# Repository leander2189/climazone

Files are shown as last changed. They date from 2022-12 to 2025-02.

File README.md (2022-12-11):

# ClimaZone

Room console interface to Airzone control system, meant to replace old panels, like this one:

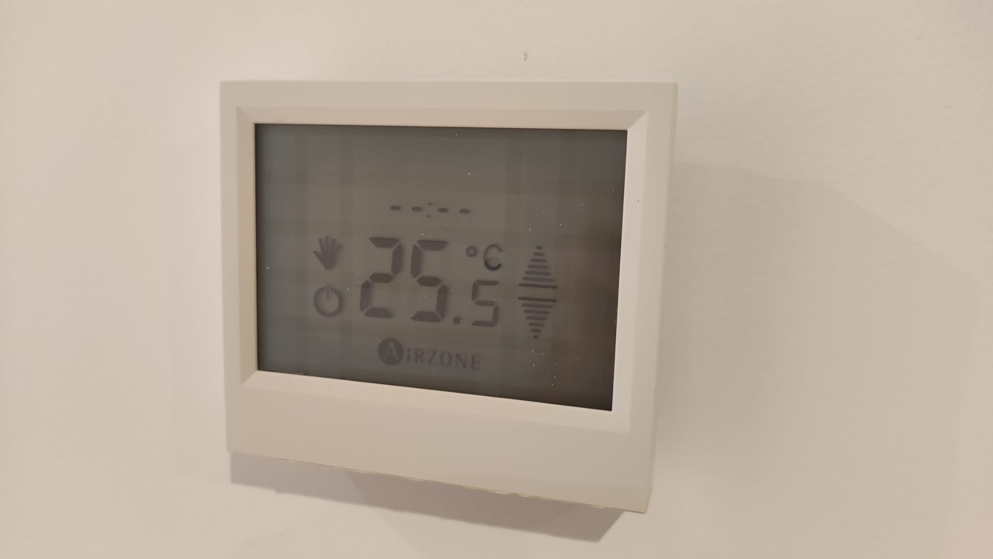
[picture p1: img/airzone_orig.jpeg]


## Bill of materials
 - ESP32 DevKit V1 DOIT
 - TFT Touch screen 2.8" 240x320 (SD + SPI)
 - BME280 I2C
 - DS18B20
 - PC817 x 4
 - 1k resistor x 4
 - 5k resistor x 1

## PCB Design
PCB design has been carried out using Kicad 6.0. The PCB is compatible both with master and slave consoles.

The temperature console is based on an ESP32 with a touch screen as an interface. It uses a DS18B20 for temperature measurement and a BME280 to measure humidity and pressure. Finally, the outputs are activated using PC817 optocouplers.

In the project there have been used 3 kicad libraries, which are already packaged:
 - https://gitlab.com/VictorLamoine/kicad/-/tree/master/ @ Victor Lamoine
 - https://github.com/colesnicov/kicad-TFT-Displays @ Colesnicov Denis
 - https://github.com/Pingoin/Pingolib-Kicad @ Pingoin

PCB Front               |  PCB Rear
:----------------------:|:-----------------------:
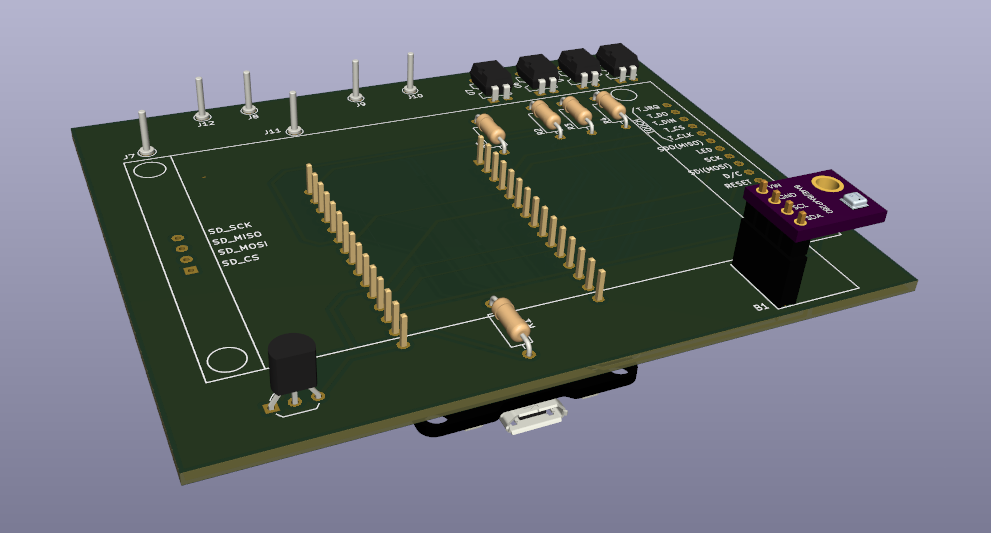
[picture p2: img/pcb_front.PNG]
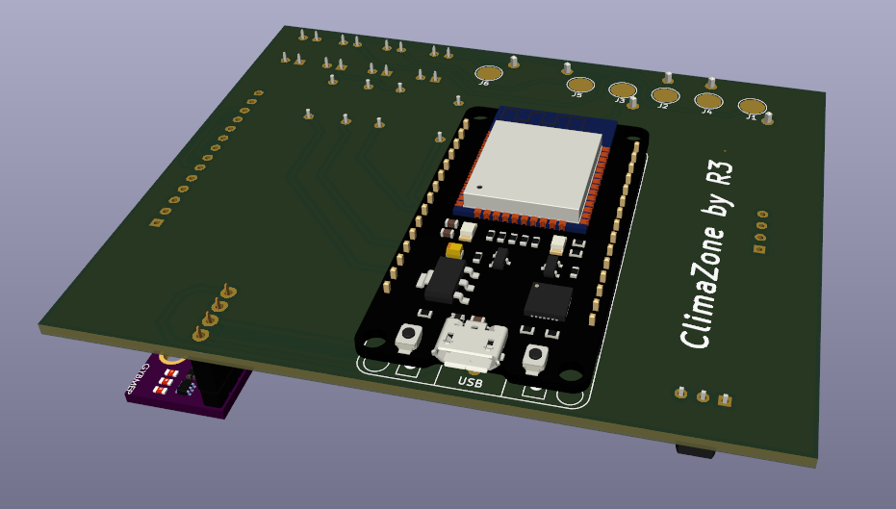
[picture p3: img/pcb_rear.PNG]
  |  

## Case design and installation
The case is designed to replace the old control panel, thus using the same interface bolts, as can be seen in the following picture.

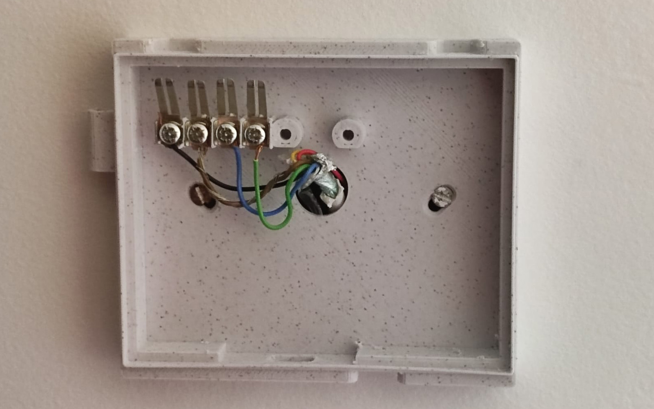
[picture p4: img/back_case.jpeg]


The design is composed of 2 elements, all of them can be 3D printed:
- The bottom part, which is bolted to the wall
- The top part, which encloses the PCB

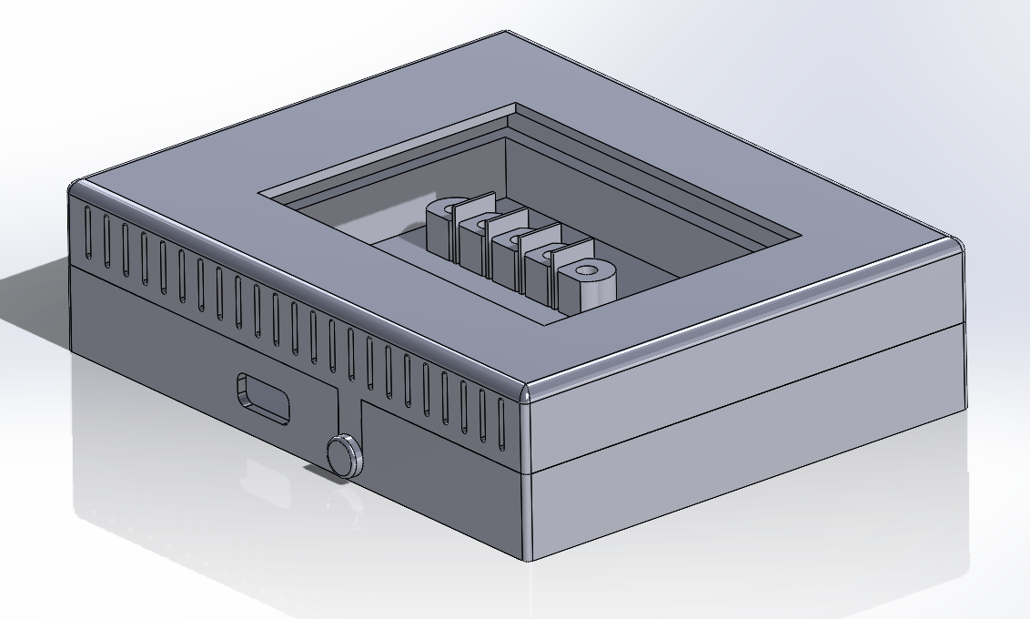
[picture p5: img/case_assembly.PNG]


## Software (TODO)
The software included measures temperature, humidity and pressure every 5s, showing this information on the display. Additionally, when pushing on the On/Off button, the goal temperature will be set up. This goal is used to activate the air conditioner.

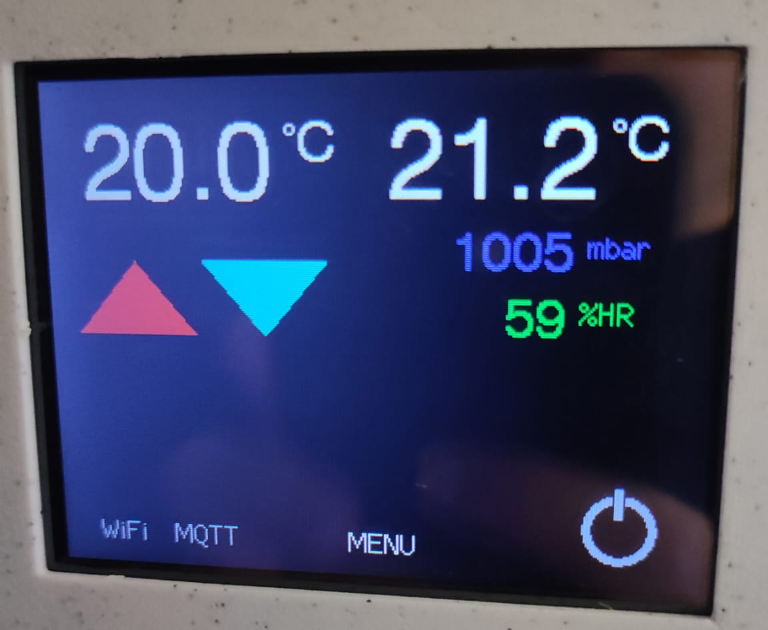
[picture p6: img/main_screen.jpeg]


Also a menu screen is added, to configure several parameters of the console:
- Temperature offset, to adjust the readings
- Master/slave mode
- Calibrate screen
- Restore screen calibration defaults
- Restart system

Configuration values are saved in the EEPROM of the ESP32.

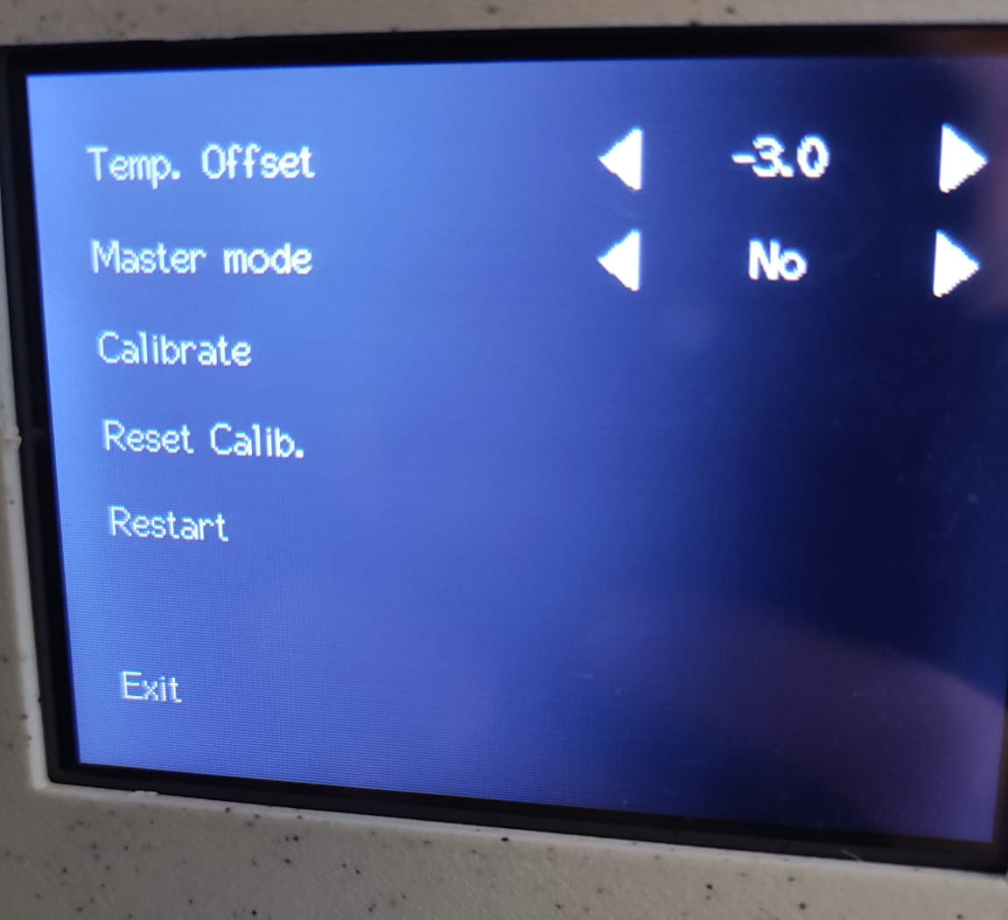
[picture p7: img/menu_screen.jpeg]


TODO list:
- [ ] Connect with Wifi
- [ ] Integration with Home Assistant
- [ ] Provide keyboard to set Wifi password

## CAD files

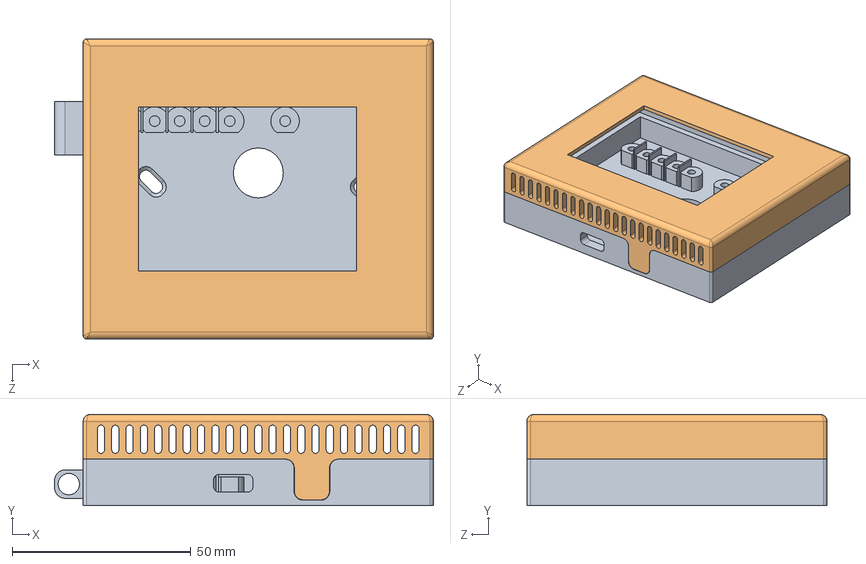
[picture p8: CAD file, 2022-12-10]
case/Ensamblaje.SLDASM
106.0 x 25.5 x 84.0 mm
SoporteClimaZone
TapaClimaZone

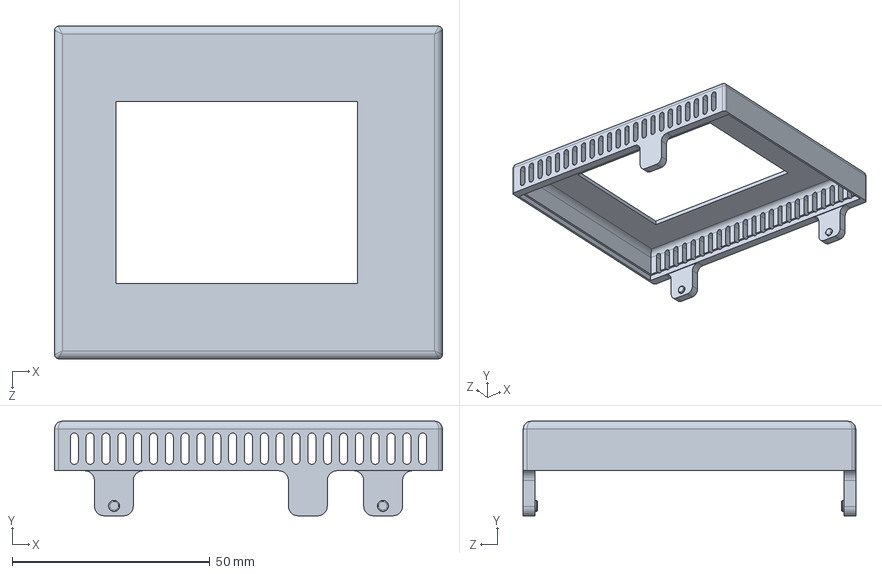
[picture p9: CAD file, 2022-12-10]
case/TapaClimaZone.SLDPRT
98.0 x 23.9 x 84.0 mm

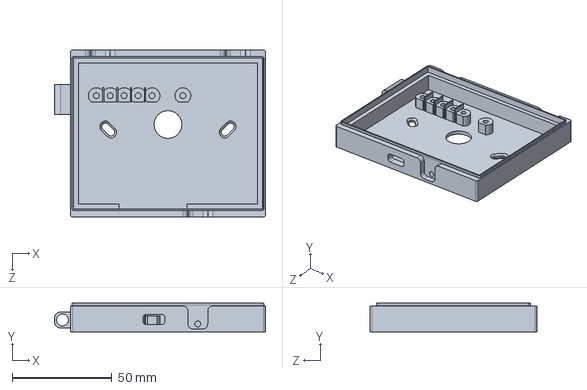
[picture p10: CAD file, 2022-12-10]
case/SoporteClimaZone.SLDPRT
106.0 x 14.5 x 84.0 mm

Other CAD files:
case/SoporteClimaZone.STL
case/TapaClimaZone.STL

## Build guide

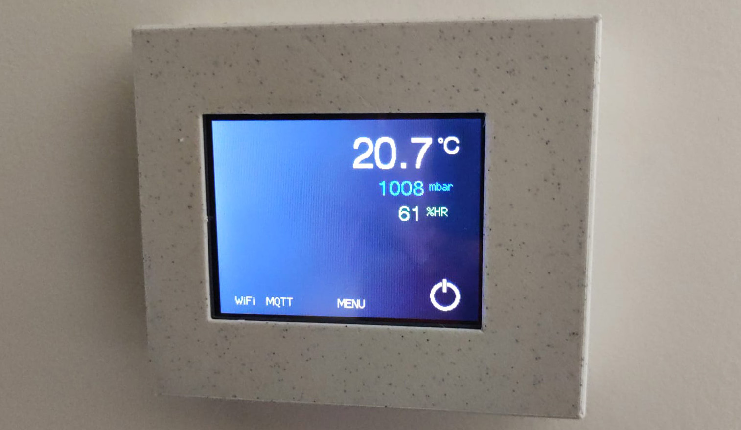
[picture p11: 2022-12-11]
img/assembled.jpeg

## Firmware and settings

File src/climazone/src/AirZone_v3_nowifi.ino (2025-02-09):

#include <Adafruit_BME280.h>
#include <OneWire.h>
#include <DallasTemperature.h>

#include <SPI.h>
#include <TFT_eSPI.h>

#include <WiFi.h>
#include <WebServer.h>
#include <Preferences.h>

#include <esp_task_wdt.h>

#include <SinricPro.h>
#include <SinricProThermostat.h>

#include <ArduinoOTA.h>

#define WDT_TIMEOUT 120




Adafruit_BME280 bmp;
TFT_eSPI tft = TFT_eSPI();       // Invoke custom library
OneWire oneWire(32);
DallasTemperature temp_sensor(&oneWire);
WebServer web_server(80);


float temp_offset = 0.0;
float temp = 21.0;
float temp2 = 22.0;
float pres = 1013;
float hr = 50.0;


// Factory settings for screen calib
uint16_t calData_[5] = { 427, 3445, 323, 3434, 7 };
// Actual settings for screen calib
uint16_t calData[5];

float set_temp = 20.0;

long lastMsg = 0;
long lastMeas = -1000000;
long lastTouch = 0;
long lastOnOff = 0;

long lastSent_Temp = 0;
long lastSent_SetTemp = 0;
float last_SetTemp = 0;

Preferences preferences;

// Salidas digitales
const int outQ1 = 33; // Demanda de frío
const int outQ2 = 27; // Demanda de calor
const int outQ3 = 12;
const int outQ4 = 13;


bool led_state = false;
const int screenBL = 25;

bool airzone_active = false;
bool touch_debug = false;


int ClimaMode = 0; // 0 ninguno, 1 frío, 2 calor

#define LEDC_CHANNEL_0     0
#define LEDC_TIMER_13_BIT  8
#define LEDC_BASE_FREQ     5000


float coseno[12] = {1.0f, 0.8660f, 0.5f, 0.0f, -0.5f, -0.8660f, -1.0f, -0.8660f, -0.5f, 0.0f, 0.5f, 0.8660f };
float seno[12] = {0.0f, 0.5f, 0.8660f, 1.0f, 0.8660f, 0.5f, 0.0f, -0.5f, -0.8660f, -1.0f, -0.8660f, -0.5f };

// Cambiando el valor de darkMode se puede alternar en la versión light o dark
const bool darkMode = true;
const uint32_t FRONT_COL = darkMode ? TFT_WHITE : TFT_BLACK;
const uint32_t BACK_COL = darkMode ? TFT_BLACK : TFT_WHITE;
const uint32_t GRAY_COL = darkMode ? TFT_DARKGREY : TFT_LIGHTGREY;


bool MASTER_MODE = true;
bool is_OTA_ongoing = false;

// Variables del menú
enum MenuModes { MAIN_SCREEN, MENU, WIFI_SETUP};
MenuModes MENU_MODE = MAIN_SCREEN;
int currMenuPage = 0;
const int MenuPages = 2;

// Ajustar el valor mínimo de la pantalla en modo "sleep"
int MIN_BACKLIGHT = 15;
float Hysteresis;

// Internet settings
String Wifi_ssid;
String Wifi_password;
String Sinric_key;
String Sinric_secret;
String Device_id;
String Device_name;


void setup() {
  
  Serial.begin(115200);
  Serial.println("Configuring WDT...");
  esp_task_wdt_init(WDT_TIMEOUT, true); //enable panic so ESP32 restarts
  esp_task_wdt_add(NULL); //add current thread to WDT watch

  // Configuramos salidas digitales del Climazone
  pinMode(outQ1, OUTPUT);
  digitalWrite(outQ1, LOW);
  pinMode(outQ2, OUTPUT);
  digitalWrite(outQ2, LOW);
  pinMode(outQ3, OUTPUT);
  digitalWrite(outQ3, LOW);
  pinMode(outQ4, OUTPUT);
  digitalWrite(outQ4, LOW);

  ledcSetup(LEDC_CHANNEL_0, LEDC_BASE_FREQ, LEDC_TIMER_13_BIT);
  ledcAttachPin(screenBL, LEDC_CHANNEL_0);
  
  bmp.begin(0x76); // Dirección I2C del dispositivo, encontrada con I2C-Scanner
  temp_sensor.begin();
  
  tft.init();
  tft.setRotation(1);

  // Load Data from EEPROM
  load_data_eeprom();
  // Configure touch screen
  tft.setTouch(calData);

  tft.fillScreen(BACK_COL);
  draw_onoff_button();

  //while (!Serial && (millis() <= 1000));

  // Connect to wifi
  init_wifi();

  // Connect to Sinric
  init_sinric();

  // Init OTA
  init_OTA();


}

// Configuration settings
void load_data_eeprom()
{
  if (!preferences.begin("settings", false))
    Serial.println("Failed to initialize settings memory");
  else
    Serial.println("Loading settings from memory");

  MASTER_MODE = preferences.getBool("master_mode", false);
  temp_offset = preferences.getFloat("temp_offset", 0.0f);
  MIN_BACKLIGHT = preferences.getInt("min_backlight", MIN_BACKLIGHT);
  Hysteresis = preferences.getFloat("hysteresis", 0.1);

  // Load touch screen calibration
  calData[0] = preferences.getUShort("caldata_0", calData_[0]);
  calData[1] = preferences.getUShort("caldata_1", calData_[1]);
  calData[2] = preferences.getUShort("caldata_2", calData_[2]);
  calData[3] = preferences.getUShort("caldata_3", calData_[3]);
  calData[4] = preferences.getUShort("caldata_4", calData_[4]);

  touch_debug = preferences.getBool("touch_debug", false);

  // Load internet settings
  Wifi_ssid = preferences.getString("wifi_ssid", "");
  Wifi_password = preferences.getString("wifi_password", "");
  Sinric_key = preferences.getString("sinric_key", "");
  Sinric_secret = preferences.getString("sinric_secret", "");
  Device_id = preferences.getString("device_id", "");
  Device_name = preferences.getString("device_name", "");

  preferences.end();
}

void save_data_eeprom()
{
  if (!preferences.begin("settings", false))
    Serial.println("Failed to initialize settings memory");

  preferences.putBool("master_mode", MASTER_MODE);
  preferences.putFloat("temp_offset", temp_offset);
  preferences.putInt("min_backlight", MIN_BACKLIGHT);
  preferences.putFloat("hysteresis", Hysteresis);

  // Save touch screen calibration
  preferences.putUShort("caldata_0", calData[0]);
  preferences.putUShort("caldata_1", calData[1]);
  preferences.putUShort("caldata_2", calData[2]);
  preferences.putUShort("caldata_3", calData[3]);
  preferences.putUShort("caldata_4", calData[4]);

  preferences.putBool("touch_debug", touch_debug);

  // Load internet settings
  preferences.putString("wifi_ssid", Wifi_ssid);
  preferences.putString("wifi_password", Wifi_password);
  preferences.putString("sinric_key", Sinric_key);
  preferences.putString("sinric_secret", Sinric_secret);
  preferences.putString("device_id", Device_id);
  preferences.putString("device_name", Device_name);

  preferences.end();
}

// Touch screen
bool get_pressed_point(long now, uint16_t* x, uint16_t* y)
{
  // Pressed will be set true is there is a valid touch on the screen
  const uint16_t threshold = 600u;
  bool pressed = tft.getTouch(x, y, threshold);
  if (pressed) lastTouch = now;

  return pressed;
}

void calibrate_touch()
{
    tft.fillScreen(BACK_COL);
    tft.setCursor(20, 0);
    tft.setTextFont(2);
    tft.setTextSize(1);
    tft.setTextColor(FRONT_COL, BACK_COL);

    tft.println("Touch corners as indicated");

    delay(500);

    tft.setTextFont(1);
    tft.println();

    tft.calibrateTouch(calData, TFT_MAGENTA, BACK_COL, 15);
    tft.setTouch(calData);
    tft.setTextColor(TFT_GREEN, BACK_COL);
    tft.println("Calibration complete!");

    Serial.printf("Touch Calibration Data: [%d, %d, %d, %d, %d]\n", calData[0], calData[1], calData[2], calData[3], calData[4]);

    delay(500);
    tft.fillScreen(BACK_COL);
}

// Drawing utilities
void draw_onoff_button()
{
    uint32_t onoff_color = airzone_active ? FRONT_COL : GRAY_COL;
    tft.fillCircle(280, 210, 17, onoff_color);
    tft.fillCircle(280, 210, 13, BACK_COL);
    tft.fillRect(280-3, 210-20, 6, 10, BACK_COL);
    tft.fillRect(280-2, 210-20, 4, 15, onoff_color);
}

void draw_current_temp()
{
   // Escribimos temperatura
    tft.setTextColor(FRONT_COL, BACK_COL);  // Text colour
    tft.setTextFont(6);
    int txt_x = 170;
    txt_x += tft.drawFloat(temp2, 1, txt_x, 20);
    tft.setTextFont(1);
    txt_x += tft.drawString(" o", txt_x, 20);
    tft.setTextFont(4);
    txt_x += tft.drawString("C", txt_x, 20);

    // Escribimos presión
    tft.setTextColor(TFT_BLUE, BACK_COL);  // Text colour
    tft.setTextFont(4);
    txt_x = 200;
    if (pres < 1000) txt_x += tft.drawString(" ", txt_x, 70); // Handle padding
    txt_x += tft.drawNumber(int(pres),txt_x, 70);
    tft.setTextFont(2);
    tft.drawString(" mbar", txt_x, 70);
    
    // Escribimos humedad relativa
    tft.setTextColor(TFT_GREEN, BACK_COL);  // Text colour
    tft.setTextFont(4);
    txt_x = 225;
    txt_x += tft.drawNumber(int(hr), txt_x, 100);
    tft.setTextFont(2);
    tft.drawString(" %HR", txt_x, 100);
  
}

void draw_sun(int x0, int y0, int r, uint32_t color)
{
  tft.fillCircle(x0, y0, r - 3, color);
  for (int i = 0; i < 12; i++)
  {
      float cx = coseno[i];//cosf(30.0f * i);
      float sx = seno[i];//sinf(30.0f * i);
      int x1 = round(x0 + (r-1)*cx);
      int x2 = round(x0 + (r+2)*cx);
      int y1 = round(y0 + (r-1)*sx);
      int y2 = round(y0 + (r+2)*sx);
      tft.drawLine(x1,y1, x2,y2, color);
  }
}

void draw_snow(int x0, int y0, int r, uint32_t color)
{

  for (int i = 0; i < 6; i++)
  {
    float cx = coseno[2*i];//(60.0f * i);
    float sx = seno[2*i];//sinf(60.0f * i);

    tft.drawLine(x0, y0, round(x0 + r*cx), round(y0 + r*sx), color);

    int px1 = round(x0 + 0.5*r*cx);
    int py1 = round(y0 + 0.5*r*sx);

    int idx_izq = i > 0 ? 2*i - 1 : 11;
    int idx_dch = i < 6 ? 2*i + 1 : 1;

    int px2 = round(x0 + 0.75*r*coseno[idx_izq]);
    int py2 = round(y0 + 0.75*r*seno[idx_izq]);

    int px3 = round(x0 + 0.75*r*coseno[idx_dch]);
    int py3 = round(y0 + 0.75*r*seno[idx_dch]);

    tft.drawLine(px1, py1, px2, py2, color);
    tft.drawLine(px1, py1, px3, py3, color);
  }

}

bool set_screen_backlight(long lastTouch, long now, bool forced)
{
  if (forced) {
    ledcWrite(LEDC_CHANNEL_0, 255);
    return true;
  }

  const long t1 = 5000;
  const long t2 = t1 + 3000;

  if (now - lastTouch < t1) {
    ledcWrite(LEDC_CHANNEL_0, 255);
    return true;
  }
  else if (now - lastTouch < t2) {
    float y = 255 - (255 - MIN_BACKLIGHT)*(now - lastTouch - t1)/(float)(t2 - t1);
    ledcWrite(LEDC_CHANNEL_0, (int)y);
    return true;
  }
  else {
    ledcWrite(LEDC_CHANNEL_0, MIN_BACKLIGHT);
    return false;
  }
}

void meas_values(long now)
{
    if (now - lastMeas < 30000ul) return;

    temp_sensor.requestTemperatures(); 
    temp = bmp.readTemperature();
    pres = bmp.readPressure()/100;
    hr = bmp.readHumidity();
    temp2 = temp_sensor.getTempCByIndex(0) + temp_offset;

    Serial.printf("Temp (18DS20): %.1fºC | Temp (BMP): %.1fºC | Pressure: %.0f mbar | HR: %.0f %%\n", temp2, temp, pres, hr);
    
    lastMeas = now;
}
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
void loop() 
{
  long now = millis();
  esp_task_wdt_reset();

  ArduinoOTA.handle();
  if (is_OTA_ongoing) return; 

  SinricPro.handle();

  switch (MENU_MODE)
  {
  case MAIN_SCREEN:
    handle_main_screen(now);
    break;
  case MENU:
    handle_menu_screen(now);
    break;
  case WIFI_SETUP:
    handle_webserver_screen(now);
    break;
  default:
    break;
  }
}

// Funciones de conectividad
void init_wifi()
{
  if (Wifi_ssid == "") return; // Check that there is a network defined

  Serial.print("Connecting to ");
  Serial.println(Wifi_ssid);
  WiFi.begin(Wifi_ssid, Wifi_password);

  while (WiFi.status() != WL_CONNECTED) {
    delay(500);
    Serial.print(".");
  }

  Serial.println("");
  Serial.println("WiFi connected");
  Serial.println("IP address: ");
  Serial.println(WiFi.localIP());
  Serial.printf("RSSI: %d dBm\r\n", WiFi.RSSI());
}

void set_webserver()
{
  Serial.println("Setting wifi connection");
  MENU_MODE = WIFI_SETUP;
  tft.fillScreen(BACK_COL);

  // Init wifi as AP
  WiFi.mode(WIFI_MODE_AP);
  Serial.print("Setting up WiFi AP...");
  String ap_name = "ESP_" + WiFi.macAddress();
  ap_name.replace(":", "_");
  WiFi.softAP(ap_name);

  IPAddress IP = WiFi.softAPIP();
  Serial.print("AP IP address: ");
  Serial.println(IP);

  tft.setTextFont(2);
  tft.setTextColor(FRONT_COL, BACK_COL);
  tft.drawString("1. Connect to WiFi network:", 30, 30);
  tft.setTextColor(TFT_GREEN, BACK_COL);
  tft.drawString(ap_name, 30, 50);

  tft.setTextColor(FRONT_COL, BACK_COL);
  tft.drawString("2. Open web address:", 30, 80);
  tft.setTextColor(TFT_GREEN, BACK_COL);
  tft.drawString(IP.toString(), 30, 110);
  tft.setTextColor(FRONT_COL, BACK_COL);
  tft.drawString("3. Fill in form", 30, 140);

  tft.setTextColor(TFT_RED, BACK_COL);
  tft.drawString("Exit", 20, 200);

  web_server.on("/", handle_OnConnect);
  web_server.on("/post", handle_OnSubmit);
  web_server.onNotFound(handle_NotFound);
  web_server.begin();
}

void handle_OnConnect() 
{
  Serial.println("HTML requested");
  web_server.send(200, "text/html", SendHTML()); // 3
}

void handle_NotFound()
{
  web_server.send(404, "text/plain", "La pagina no existe");
}

void handle_OnSubmit()
{

  int n_args = web_server.args();
  Serial.printf("Request got with %d args \n", n_args);

  // Cogemos parámetros
  if (n_args == 6) {
    Wifi_ssid = web_server.arg(0);
    Serial.printf("SSID_Name = %s\n", Wifi_ssid.c_str());
    Wifi_password = web_server.arg(1);
    Serial.printf("Password = %s\n", Wifi_password.c_str());
    Sinric_key = web_server.arg(2);
    Serial.printf("Sinric_Key = %s\n", Sinric_key.c_str());
    Sinric_secret = web_server.arg(3);
    Serial.printf("Sinric Secret = %s\n", Sinric_secret.c_str());
    Device_id = web_server.arg(4);
    Serial.printf("Device_Id = %s\n", Device_id.c_str());
    Device_name = web_server.arg(5);
    Serial.printf("Device_Name = %s\n", Device_name.c_str());
  } else {
      Serial.println("Not expected number of args");
  }

  web_server.send(200, "text/plain", "OK");

  // Mostramos info en la pantalla
  tft.fillScreen(BACK_COL);
  tft.setTextFont(2);
  tft.setTextColor(FRONT_COL, BACK_COL);
  tft.drawString("Updating settings...", 30, 30);

  // Guardamos la eeprom
  save_data_eeprom();

  // Cerramos el servidor web
  web_server.close();
  
  // Conectamos wifi
  tft.drawString("Connecting to WiFi...", 30, 60);
  init_wifi();
  init_sinric();
  init_OTA();

  // Volvemos a pantalla principal
  tft.fillScreen(BACK_COL);
  draw_onoff_button();
  MENU_MODE = MAIN_SCREEN;
}

void handle_webserver_screen(long now)
{
  web_server.handleClient();

  // Check press event
  bool pressed = false;
  uint16_t x = 0, y = 0; // To store the touch coordinates
  if (now - lastTouch > 200) pressed = get_pressed_point(now, &x, &y);
  // Botón Exit
  if (x >= 20 && x <= 75 && y >= 200 && y <= 216)
  {
    // Cerramos el servidor web
    web_server.close();
  
    // Volvemos a pantalla principal
    tft.fillScreen(BACK_COL);
    draw_onoff_button();
    MENU_MODE = MAIN_SCREEN;
    return;
  }
}

String SendHTML() 
{
  // Cabecera de todas las paginas WEB
  String ptr = R"rawliteral(
<!DOCTYPE html>
<html lang="en">
<head>
<meta charset="UTF-8">
<meta name="viewport" content="width=device-width, initial-scale=1.0">
<title>WiFi Settings</title>
<style>
    body {
        font-family: Arial, sans-serif;
        margin: 0;
        padding: 0;
        display: flex;
        justify-content: center;
        align-items: center;
        height: 100vh;
        background-color: #f2f2f2;
    }
    .container {
        background-color: #fff;
        padding: 20px;
        border-radius: 8px;
        box-shadow: 0px 0px 10px 0px rgba(0,0,0,0.1);
    }
    .form-group {
        margin-bottom: 20px;
    }
    .form-group label {
        display: block;
        font-weight: bold;
        margin-bottom: 5px;
    }
    .form-group input {
        width: 100%;
        padding: 10px;
        border: 1px solid #ccc;
        border-radius: 4px;
        box-sizing: border-box;
        font-size: 16px;
    }
    .btn-submit {
        background-color: #4CAF50;
        color: white;
        padding: 10px 20px;
        border: none;
        border-radius: 4px;
        cursor: pointer;
        font-size: 16px;
    }
    .btn-submit:hover {
        background-color: #45a049;
    }
</style>
</head>
<body>

<div class="container">
    <h2>WiFi Settings</h2>
    <form id="wifi-form" action="/post">
        <div class="form-group">
            <label for="ssid">SSID Name:</label>
            <input type="text" id="ssid" name="ssid" required>
        </div>
        <div class="form-group">
            <label for="password">WiFi Password:</label>
            <input type="password" id="password" name="password">
        </div>
        <div class="form-group">
            <label for="app-key">Sinric App Key:</label>
            <input type="text" id="app-key" name="app-key">
        </div>
        <div class="form-group">
            <label for="app-secret">Sinric App Secret:</label>
            <input type="text" id="app-secret" name="app-secret">
        </div>
        <div class="form-group">
            <label for="device-id">Device Id:</label>
            <input type="text" id="device-id" name="device-id">
        </div>
        <div class="form-group">
            <label for="device-name">Device Name:</label>
            <input type="text" id="device-name" name="device-name">
        </div>
        <button type="submit" class="btn-submit">Submit</button>
    </form>
</div>

</body>
</html>
  )rawliteral"; 
  return ptr;
}

// Funciones de Sinric
void init_sinric() 
{
  if (!WiFi.isConnected()) return;

  SinricProThermostat &myThermostat = SinricPro[Device_id];
  myThermostat.onPowerState(onPowerState);
  myThermostat.onTargetTemperature(onTargetTemperature);
  myThermostat.onAdjustTargetTemperature(onAdjustTargetTemperature);
  myThermostat.onThermostatMode(onThermostatMode);

  // setup SinricPro
  SinricPro.onConnected([](){ Serial.println("[Sinric] Connected to SinricPro"); }); 
  SinricPro.onDisconnected([](){ Serial.println("[Sinric] Disconnected from SinricPro"); });
  Serial.printf("Sinric Key: %s\n", Sinric_key.c_str());
  Serial.printf("Sinric secret: %s\n", Sinric_secret.c_str());
  Serial.printf("Sinric device id: %s\n", Device_id.c_str());
  SinricPro.begin(Sinric_key, Sinric_secret);
}

bool onPowerState(const String &deviceId, bool &state) 
{
  set_airzone_active(state);
  Serial.printf("[Sinric] Thermostat %s turned %s\r\n", deviceId.c_str(), state ?"on":"off");

  return true; // request handled properly
}

bool onTargetTemperature(const String &deviceId, float &temperature) 
{
  set_temp = temperature;
  Serial.printf("[Sinric] Thermostat %s set temperature to %f\r\n", deviceId.c_str(), temperature);

  return true;
}

bool onAdjustTargetTemperature(const String & deviceId, float &temperatureDelta) 
{
  set_temp += temperatureDelta;  // calculate absolut temperature
  Serial.printf("Thermostat %s changed temperature about %f to %f", deviceId.c_str(), temperatureDelta, set_temp);

  return true;
}

bool onThermostatMode(const String &deviceId, String &mode) 
{
  Serial.printf("Thermostat %s set to mode %s\r\n", deviceId.c_str(), mode.c_str());

  if (mode == "HEAT") ClimaMode = 2;
  if (mode == "COOL") ClimaMode = 1;
  //lastTouch = millis();

  return true;
}

void sent_sinric_power(bool active)
{
  // send powerstate event
  SinricProThermostat &myThermostat = SinricPro[Device_id];
  myThermostat.sendPowerStateEvent(active); // send the new powerState to SinricPro server
}
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

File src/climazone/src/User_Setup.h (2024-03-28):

//                            USER DEFINED SETTINGS
//   Set driver type, fonts to be loaded, pins used and SPI control method etc.
//
//   See the User_Setup_Select.h file if you wish to be able to define multiple
//   setups and then easily select which setup file is used by the compiler.
//
//   If this file is edited correctly then all the library example sketches should
//   run without the need to make any more changes for a particular hardware setup!
//   Note that some sketches are designed for a particular TFT pixel width/height

// User defined information reported by "Read_User_Setup" test & diagnostics example
#define USER_SETUP_INFO "User_Setup"

// Define to disable all #warnings in library (can be put in User_Setup_Select.h)
//#define DISABLE_ALL_LIBRARY_WARNINGS

// ##################################################################################
//
// Section 1. Call up the right driver file and any options for it
//
// ##################################################################################

// Define STM32 to invoke optimised processor support (only for STM32)
//#define STM32

// Defining the STM32 board allows the library to optimise the performance
// for UNO compatible "MCUfriend" style shields
//#define NUCLEO_64_TFT
//#define NUCLEO_144_TFT

// STM32 8-bit parallel only:
// If STN32 Port A or B pins 0-7 are used for 8-bit parallel data bus bits 0-7
// then this will improve rendering performance by a factor of ~8x
//#define STM_PORTA_DATA_BUS
//#define STM_PORTB_DATA_BUS

// Tell the library to use parallel mode (otherwise SPI is assumed)
//#define TFT_PARALLEL_8_BIT
//#defined TFT_PARALLEL_16_BIT // **** 16-bit parallel ONLY for RP2040 processor ****

// Display type -  only define if RPi display
//#define RPI_DISPLAY_TYPE // 20MHz maximum SPI

// Only define one driver, the other ones must be commented out
#define ILI9341_DRIVER       // Generic driver for common displays
//#define ILI9341_2_DRIVER     // Alternative ILI9341 driver, see https://github.com/Bodmer/TFT_eSPI/issues/1172
//#define ST7735_DRIVER      // Define additional parameters below for this display
//#define ILI9163_DRIVER     // Define additional parameters below for this display
//#define S6D02A1_DRIVER
//#define RPI_ILI9486_DRIVER // 20MHz maximum SPI
//#define HX8357D_DRIVER
//#define ILI9481_DRIVER
//#define ILI9486_DRIVER
//#define ILI9488_DRIVER     // WARNING: Do not connect ILI9488 display SDO to MISO if other devices share the SPI bus (TFT SDO does NOT tristate when CS is high)
//#define ST7789_DRIVER      // Full configuration option, define additional parameters below for this display
//#define ST7789_2_DRIVER    // Minimal configuration option, define additional parameters below for this display
//#define R61581_DRIVER
//#define RM68140_DRIVER
//#define ST7796_DRIVER
//#define SSD1351_DRIVER
//#define SSD1963_480_DRIVER
//#define SSD1963_800_DRIVER
//#define SSD1963_800ALT_DRIVER
//#define ILI9225_DRIVER
//#define GC9A01_DRIVER

// Some displays support SPI reads via the MISO pin, other displays have a single
// bi-directional SDA pin and the library will try to read this via the MOSI line.
// To use the SDA line for reading data from the TFT uncomment the following line:

// #define TFT_SDA_READ      // This option is for ESP32 ONLY, tested with ST7789 and GC9A01 display only

// For ST7735, ST7789 and ILI9341 ONLY, define the colour order IF the blue and red are swapped on your display
// Try ONE option at a time to find the correct colour order for your display

//  #define TFT_RGB_ORDER TFT_RGB  // Colour order Red-Green-Blue
//  #define TFT_RGB_ORDER TFT_BGR  // Colour order Blue-Green-Red

// For M5Stack ESP32 module with integrated ILI9341 display ONLY, remove // in line below

// #define M5STACK

// For ST7789, ST7735, ILI9163 and GC9A01 ONLY, define the pixel width and height in portrait orientation
// #define TFT_WIDTH  80
// #define TFT_WIDTH  128
// #define TFT_WIDTH  172 // ST7789 172 x 320
// #define TFT_WIDTH  170 // ST7789 170 x 320
// #define TFT_WIDTH  240 // ST7789 240 x 240 and 240 x 320
// #define TFT_HEIGHT 160
// #define TFT_HEIGHT 128
// #define TFT_HEIGHT 240 // ST7789 240 x 240
// #define TFT_HEIGHT 320 // ST7789 240 x 320
// #define TFT_HEIGHT 240 // GC9A01 240 x 240

// For ST7735 ONLY, define the type of display, originally this was based on the
// colour of the tab on the screen protector film but this is not always true, so try
// out the different options below if the screen does not display graphics correctly,
// e.g. colours wrong, mirror images, or stray pixels at the edges.
// Comment out ALL BUT ONE of these options for a ST7735 display driver, save this
// this User_Setup file, then rebuild and upload the sketch to the board again:

// #define ST7735_INITB
// #define ST7735_GREENTAB
// #define ST7735_GREENTAB2
// #define ST7735_GREENTAB3
// #define ST7735_GREENTAB128    // For 128 x 128 display
// #define ST7735_GREENTAB160x80 // For 160 x 80 display (BGR, inverted, 26 offset)
// #define ST7735_ROBOTLCD       // For some RobotLCD Arduino shields (128x160, BGR, https://docs.arduino.cc/retired/getting-started-guides/TFT)
// #define ST7735_REDTAB
// #define ST7735_BLACKTAB
// #define ST7735_REDTAB160x80   // For 160 x 80 display with 24 pixel offset

// If colours are inverted (white shows as black) then uncomment one of the next
// 2 lines try both options, one of the options should correct the inversion.

// #define TFT_INVERSION_ON
// #define TFT_INVERSION_OFF


// ##################################################################################
//
// Section 2. Define the pins that are used to interface with the display here
//
// ##################################################################################

// If a backlight control signal is available then define the TFT_BL pin in Section 2
// below. The backlight will be turned ON when tft.begin() is called, but the library
// needs to know if the LEDs are ON with the pin HIGH or LOW. If the LEDs are to be
// driven with a PWM signal or turned OFF/ON then this must be handled by the user
// sketch. e.g. with digitalWrite(TFT_BL, LOW);

// #define TFT_BL   32            // LED back-light control pin
// #define TFT_BACKLIGHT_ON HIGH  // Level to turn ON back-light (HIGH or LOW)
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

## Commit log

2021-12-28 primera versión de climazone
2022-10-29 updated folder structure and pcb design
2022-10-29 add 3rd party kicad libraries into readme
2022-12-04 added case design
    [Ensamblaje.SLDASM, SoporteClimaZone.SLDPRT, TapaClimaZone.SLDPRT]
2022-12-04 added case bolt
    [Ensamblaje.SLDASM, RemacheClimaZone.SLDPRT]
2022-12-04 added pcb images
2022-12-10 updated 3d model of the case
    [Ensamblaje.SLDASM, SoporteClimaZone.SLDPRT, SoporteClimaZone.STL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]
2022-12-10 removed pin model (not needed anymore)
    [RemacheClimaZone.SLDPRT]
